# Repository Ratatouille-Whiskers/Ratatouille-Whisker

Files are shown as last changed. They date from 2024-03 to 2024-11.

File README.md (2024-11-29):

# Ratatouille-Whisker



Watch the video (https://www.youtube.com/watch?v=xYr4nw6rwZE)

## Bill of Materials

| Part | Description | Quantity | Cost |
| --- | --- | --- | --- |
| 3-axis Magnetometer | [Adafruit Wide-Range Triple-axis Magnetometer - MLX90393](https://www.adafruit.com/product/4022) | 1 | £10-£20 |
| Microcontroller | [Raspberry Pi Pico](https://www.raspberrypi.com/products/raspberry-pi-pico/) | 1 | £4-£12  |
| 3D Printer Filament | [eSun PLA 1kg Spool](https://esun3dstore.com/collections/pla/products/esun-epla-lite-1-75mm-3d-filament-1kg) | 1 | £18 |
| Silicone | [BBDINO Super Elastic Silicone](https://www.bestbuysilicone.com/collections/all-bbdino-product/products/bbdino-super-elastic-silicone-mold-making-rubber-platinum-trial-kit) | 1 | £28 |
| Magnet | [1 Tube (10 disks) of 5mm x 2mm Magnet](https://uk.rs-online.com/web/p/neodymium-magnets/2192248) | 1 | £8 |
| Demolding Agents | [Demoulding Vaseline](https://en.pebeo.com/catalogue/vaseline-de-demoulage-gedeo) | 1 | £6 |

## Tools & Equipment

- Required
  - 3D Printer (0.4mm nozzle)
  - Soldering Iron
  - Craft Knife (or equivalent)
- Recommended
  - Prusaslicer (2.7.0 or higher)
  - Deburring Tool

## Software Setup

### General Information

Ratatouille-Whisker is powered by a Raspberry Pi Pico. The Pi Pico was chosen for its low cost and dual-core architecture. One core is responsible for receiving and processing data from the magnetometer through I2C, and the other is responsible for transmitting the results over UART to a computer for post-processing.

The Arduino IDE was used to develop the necessary firmware. The Arduino IDE is a convenient wrapper for the Raspberry Pi Pico SDK and enables rapid prototyping. Developing using the Raspberry Pi Pico SDK is also recommended by the Ratatouille-Whisker team but would require additional development time for library integration.

The [arduino-MLX90393](https://github.com/Ratatouille-Whiskers/arduino-MLX90393) library was forked and modified from Teddy Yapo's original library (see relevant [repo](https://github.com/tedyapo/arduino-MLX90393)). The library was modified to allow I2C addresses to be defined manually in the `begin()` function. The modification was necessary as the sensor boards the team was experimenting with featured I2C addresses that did not align with the respective documentation.

A Python script is also provided as a simple serial port listener (using the `pyserial` library) and logger.

### Step 1: Arduino IDE Setup

Download the official Arduino IDE from [here](https://www.arduino.cc/en/software).

Open up the Arduino IDE and go to `File > Preferences`.
In the dialog that pops up, enter the following URL in the "Additional Boards Manager URLs" field:
```
https://github.com/earlephilhower/arduino-pico/releases/download/global/package_rp2040_index.json
```
Hit *OK* to close the dialog.
Go to `Tools > Boards > Board` Manager in the IDE and type "pico" in the search box and select the entry by "Earle F. Philhower".

[For more information visit the original repository [here](https://github.com/earlephilhower/arduino-pico).]

Open `whisker_firmware.ino` under `software/whisker_firmware` using the Arduino IDE. Select Raspberry Pi Pico as the current board.

Compilation will fail as `MLX90393.h` does not exist.

### Step 2: Install the MLX90393 Library

Go to the library's repository ([here](https://github.com/Ratatouille-Whiskers/arduino-MLX90393)) and click on `Code > Download ZIP`. The library can be installed following the instructions listed [here](https://support.arduino.cc/hc/en-us/articles/5145457742236-Add-libraries-to-Arduino-IDE). Skip to the *Importing a .zip Library* and *Manual installation* sections.

### Step 3: Upload the Code

To upload the sketch, you will need to hold the BOOTSEL button down while plugging in the Raspberry Pi Pico to your computer. Then hit the upload button and the sketch should be transferred and start to run. After the first upload, this may not be necessary as the arduino-pico core has auto-reset support.

### Step 4: Inspect Serial Monitor

In the Arduino IDE, click on `Tools > Serial Monitor` and confirm that values are being printed on the screen.

## Hardware Setup

### Printing Guide

- We provide all the **settings** for both the **Prusa MK3S** and **Prusa Mini** printers

> Other printers have not been tested.

- **`3mf`** project files can be imported directly into your slicing software (we recommend **PrusaSlicer**) for loading in all the part geometries required for printing a complete whisker assembly kit.

> Other slicers have not been tested.

- Using a **0.4mm nozzle** is recommended.

> A smaller nozzle would allow for a better result when printing the whisker shafts - but would result in higher print times. 0.25mm nozzles have been tested only for printing the shaft. Not other small sizes have been tested. Please avoid using nozzles larger than 0.4mm to ensure optimal precision and detail.

#### Slicer Settings

> We are assuming that the user has a basic understanding on how to navigate there own slicing software for their printer. Some good guides for getting familar with PrusaSlicer can be found from [Prusa's Knowledgebase](https://help.prusa3d.com/category/prusaslicer_204) and a nice TLDR-like guide from [Tomshardware](https://www.tomshardware.com/how-to/use-prusaslicer)

> If users already have their own tuned profiles for their printers, then they can try those settings and use the guidance below for some additional advice on printing.

We found the default `quality` settings (for 0.4mm nozzles) with supports enabled (tree/organics are fine to use, and can even result in a cleaner result) worked for printing, only requiring two modifications:

**The `Whisker Shaft` should be printed with a **0.1mm** layer height.**

**Setting `XY Size Compensation` in PrusaSlicer:**

> `XY Size Compensation` ensures the holes in the parts are printed with better dimensional accuracy when sliced, improving the fit of parts in each (e.g., Whisker Shaft into the Whisker Socket).

1. Navigate to the `Print Settings` Tab
2. Enable `Expert` mode in the top write of the page
3. From the navigation bar on the left, go to `Advanced`
4. Scroll down to till you get to the `Slicing` section where you will find `XY Size Compensation`.
   - Set `XY Size Compensation`, or your slicer's equivalent setting, to **-0.1mm** as a recommended starting point for tuning.

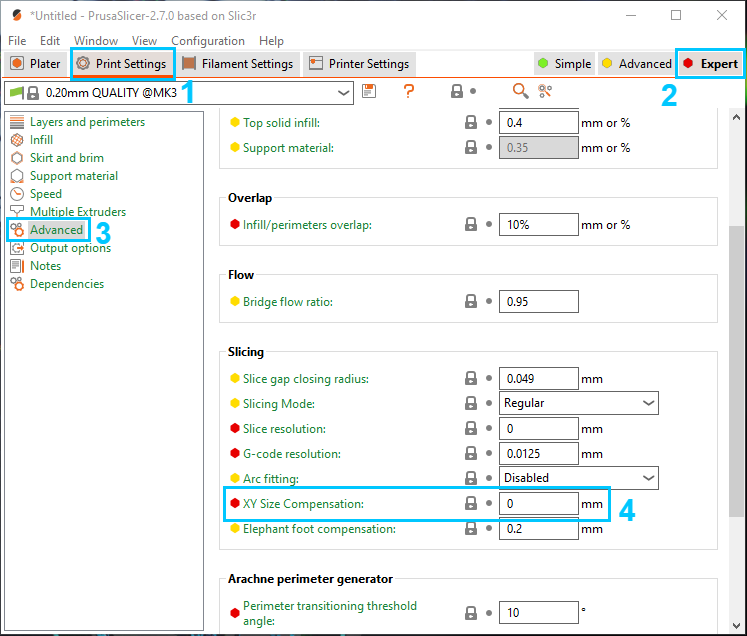
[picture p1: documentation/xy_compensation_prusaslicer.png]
PrusaSlicer XY Compenstation


##### Tuning XY Size Compensation

**DISCLAIMER: DO NOT TAKE THIS TUNING APPROACH AS 'GOOD' ADVICE ON TUNING THIS SETTING FOR ALL PRINTS. IT IS ONLY SUGGESTED FOR PRINTING THESE PARTS AND MAY NOT HELP WITH ALL PRINTS.**

**NOTE: You will need a method to measure an object's inside diameter accurately. We recommend using a set of vernier calipers.**

1. Print a `Whisker Bearing Casting Jig`
2. Print a `Whisker Socket`
3. Ensure the smaller hole of the `Whisker Socket` is approx. `3mm` in diameter
4. Ensure the larger hole of the `Whisker Socket` is approx. `5mm` in diameter
   - If the measurements are as close to "perfect" as the *true* values and the socket is snug but loose enough to fit with the casting jig that it can be easily removed, you should be fine with not tuning the compensation.
5. Set `XY Size Compensation` to `Measured - Expected`
   - Example: measured diameter `2.9mm`, expected diameter `3.0mm`, therefore we set the compensation value to `-0.1mm`
6. Ensure `Whisker Bearing Casting Jig` has a snug fit
   - Repeat this till both holes are as close to *true* as you can possibly and the socket has a snug, but loose enough, fit with the casting jig that it can be easily removed then you should be fine with not tuning the compensation.
7. Repeat steps 1-6 until you achieve high dimensional accuracy and a snug fit

The default PLA settings of the `Prusament PLA` filament profile was used for all prints.

**Note:** You may find that the fit of the `Whisker Base` is too tight in the casting jig (even with the small chamfers in the design aimed to reduce this), and it is therefore recommended to scrape each of the outer edges of the print with a knife (or deburring tool) to deburr the edges and prevent sticking, in addition to the use of mold release agent. **It is especially important for the areas of the `Whisker Base` that were on the print bed and in contact with the brim when printing.**

### Whisker Build Instructions

To Build the whisker make sure you have printed:

- 1 x Whisker Base
- 1 x Whisker Socket
- 1 x Whisker Shaft
- 1 x Whisker Bearing Casting Jig

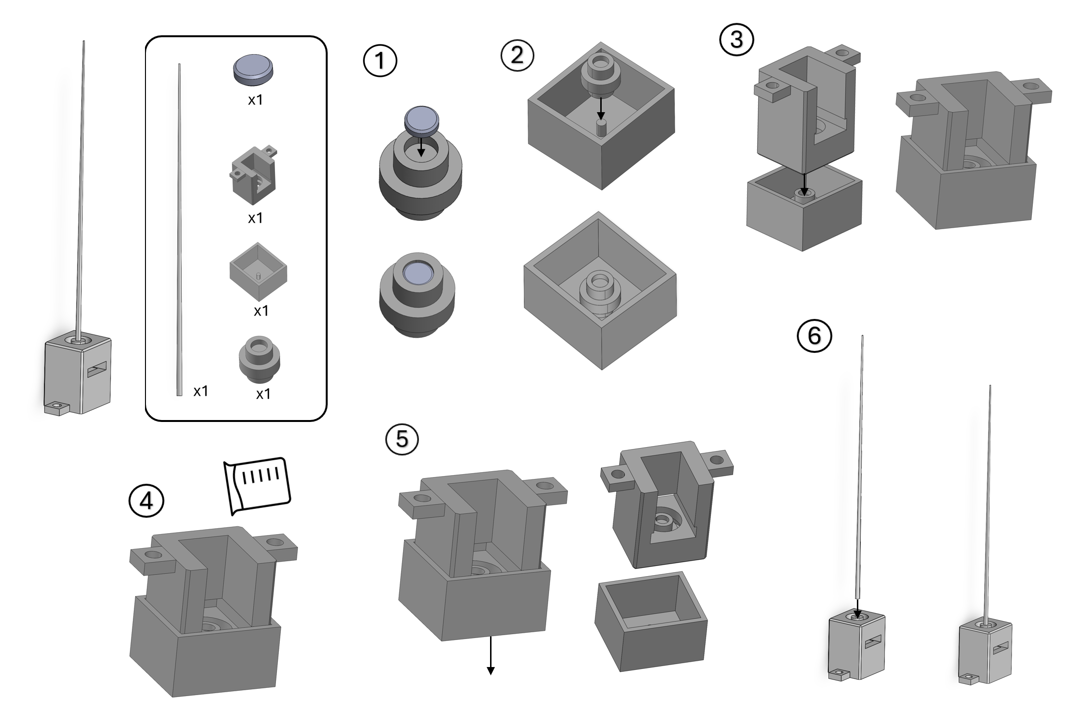
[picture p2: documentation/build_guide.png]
Build Guide Image


1. Glue the magnet into the socket.
2. Place the socket with the magnet attached into the jig. The magnet should face upwards. The pin should slot in easily to secure it in place.
3. Place the base firmly into the jig.
4. Prepare your silicone mixture as per the instructions on the packet. Then pour the silicone mixture into the hole around the socket carefully.
5. Remove the jig carefully, leaving the silicone and the socket in place.
6. Flip the base right-side-up (see image). Place the whisker into the hole in the socket at the top. This may need a gentle push to fit firmly into place.

### Sensor Wiring Instructions

The demo firmware (`whisker_firmware.ino`) implicitly indicates a recommended wiring configuration, as seen by:

```c
#define DRDY_pin 21
#define SDA_pin 16
#define SCL_pin 17
```

In detail, please adhere to the following wiring diagram (format `[SENSOR] -- [PICO]`):

- `VIN -- VBUS`
- `GND -- GND`
- `SCL -- GP17`
- `SDA -- GP17`
- `INT -- GP21`

Please consult the wiring diagram:

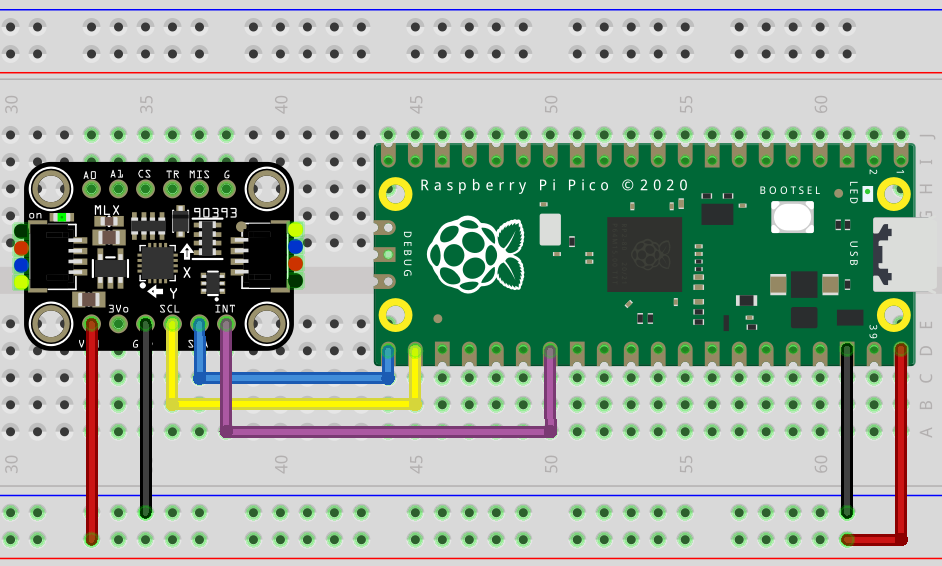
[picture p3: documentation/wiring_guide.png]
Sensor Wiring Guide Image


---

If you wish to use a STEMMA QT / Qwiic JST SH 4-Pin cable, you need only connect `INT` to `GP21` and change the defines to read:

```c
#define DRDY_pin 21
#define SDA_pin 4
#define SCL_pin 5
```

## User Guide

### Logging Data

You are free to use the Python-based script to collect data and save them in a CSV format with timestamps.
Apart from installing Python (from [here](https://www.python.org/)), you also need to install pyserial (see the [repo](https://github.com/pyserial/pyserial)) using pip:
```
pip install pyserial
```

You can now navigate to `software/whisker_listener` and run `python whisker_listener.py -h` to be greeted with useful instructions on how to use the script:

```
usage: whisker_listener.py [-h] [-b BAUD_RATE] serial_port

Read data from a serial port.

positional arguments:
  serial_port   Serial port name (e.g., COM3 or /dev/ttyACM0)

options:
  -h, --help    show this help message and exit
  -b BAUD_RATE  Baud rate (default is 115200)
```

On Linux systems, the data can be logged using:
```
python whisker_listener.py /dev/ttyACM0
```

<!-- ## General Testing
## Troubleshooting Guide -->
## Related Work

[Calibration Platform](https://github.com/FoR-Group1/OpenWhisker/tree/main/calibration_platform) - 3D Printer Based Open Source Calibration
Platform for Whisker Sensors.

**DISCLAIMER: This platform has not been tested with the design presented in this repo, therefore modification may be required to use it for our design.**

## How to Contribute?

Feel free to fork this repo and submit pull requests!

## Cite Ratatouille-Whisker

Click `Cite this repository` in the sidebar to cite the most recent version of this repo.

Alternatively, feel free to cite our publication in TAROS 2024:

```
TBA
```

## License
This work is provided under GPL license for the software source code and CERN-OHL-W license for the hardware design and build instructions.

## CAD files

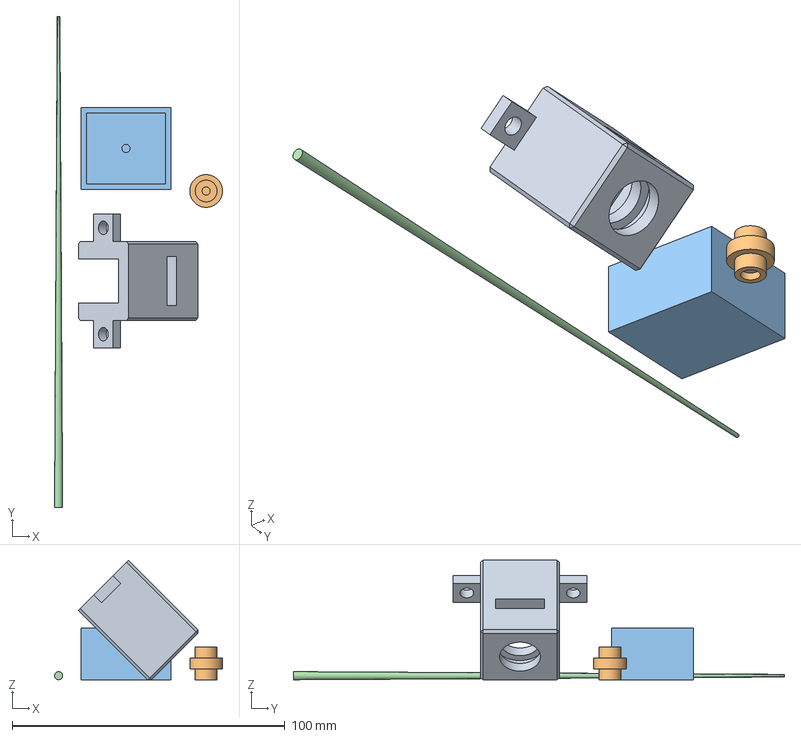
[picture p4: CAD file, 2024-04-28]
hardware/3mf/whisker_whisker_kit_mk3.3mf
61.6 x 180.0 x 43.8 mm
Whisker_Whisker_Base
Whisker_Whisker_Socket
Whisker_Bearing_Casting_Jig
Whisker_Whisker_Shaft

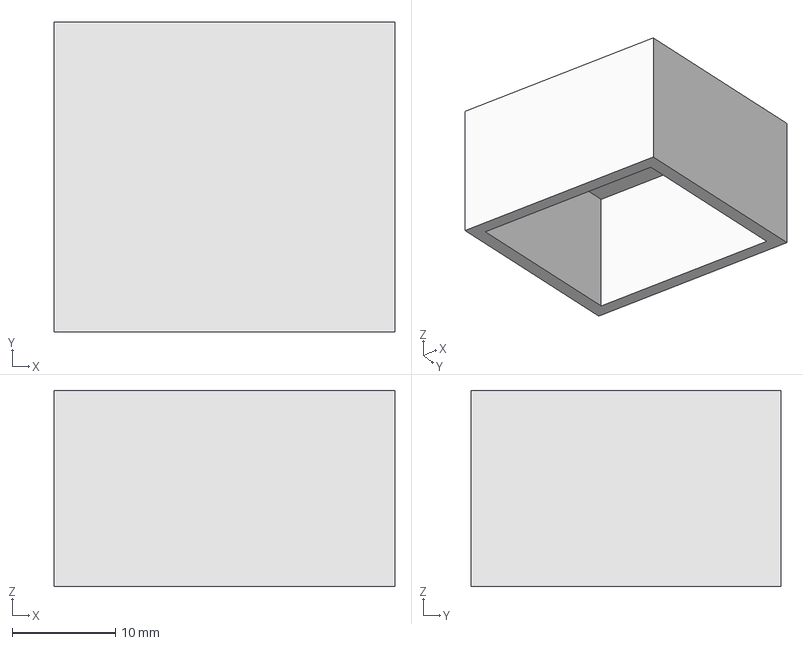
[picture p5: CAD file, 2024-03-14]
hardware/step/whisker_bearing_casting_jig.step
33.0 x 30.0 x 19.0 mm

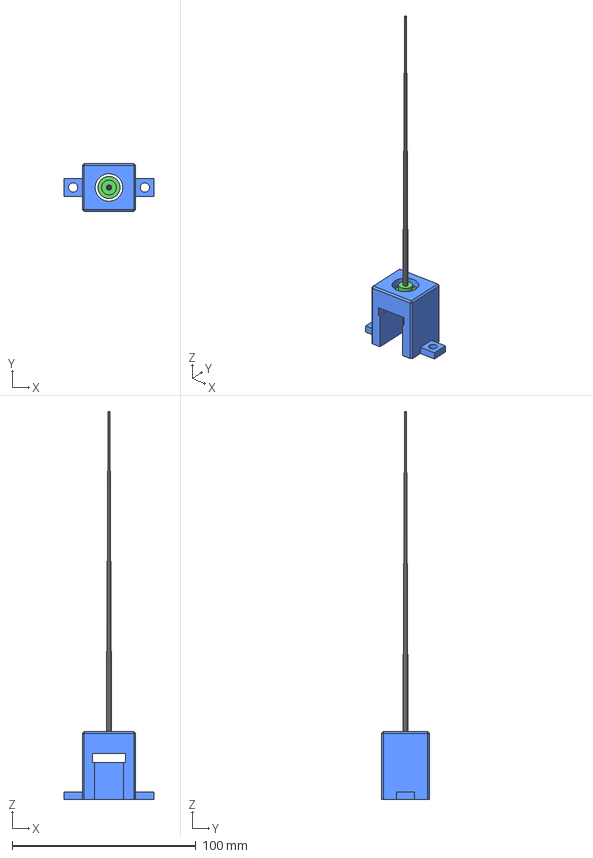
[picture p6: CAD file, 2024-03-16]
hardware/whisker.FCStd
49.0 x 26.0 x 211.0 mm
Whisker Shaft
Whisker Socket
Whisker Base

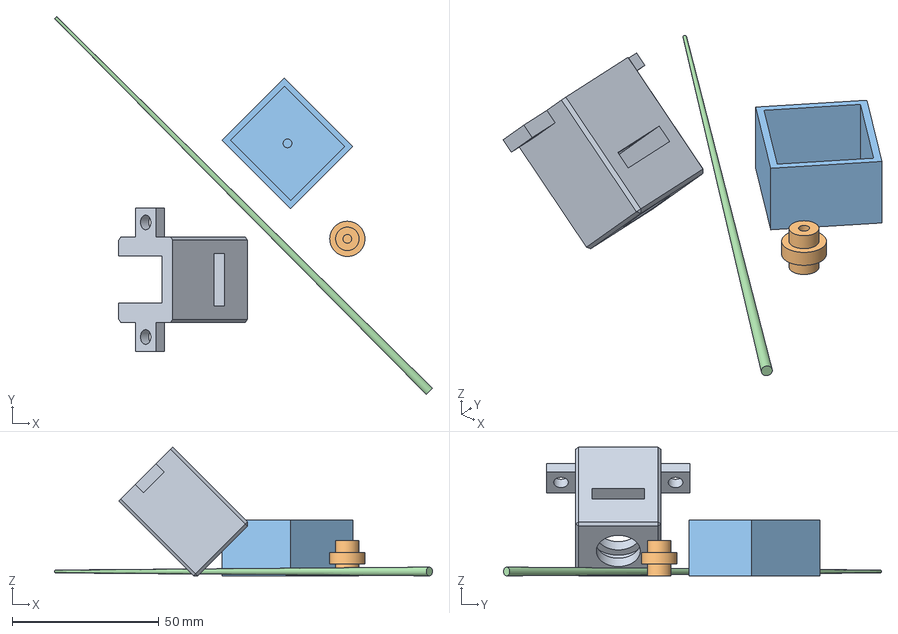
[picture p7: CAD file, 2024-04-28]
hardware/3mf/whisker_whisker_kit_mini.3mf
128.7 x 128.7 x 43.8 mm
Whisker_Whisker_Base
Whisker_Whisker_Socket
Whisker_Bearing_Casting_Jig
Whisker_Whisker_Shaft

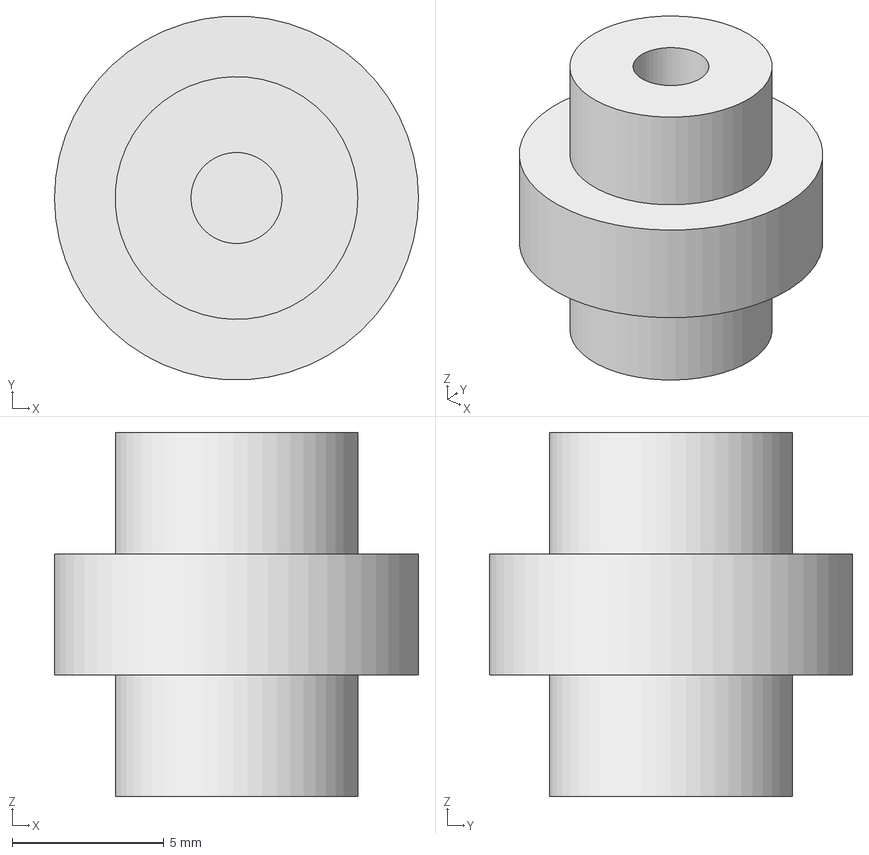
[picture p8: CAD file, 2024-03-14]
hardware/step/whisker_whisker_socket.step
12.0 x 12.0 x 12.0 mm

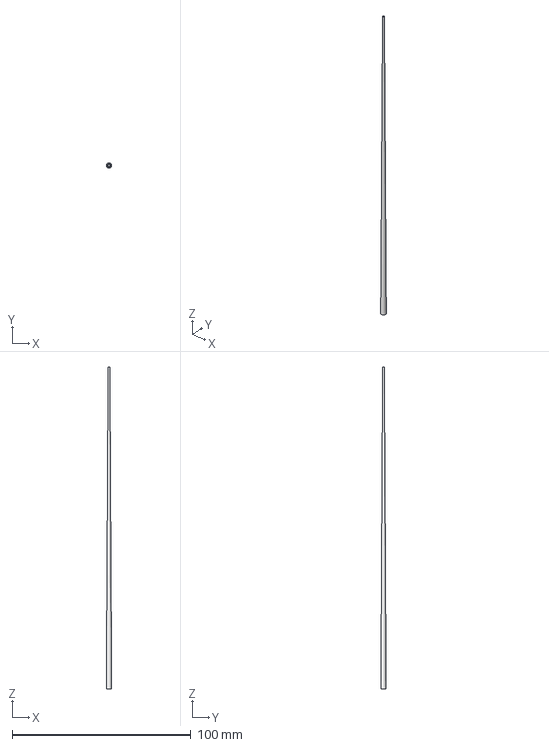
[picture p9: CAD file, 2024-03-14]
hardware/step/whisker_whisker_shaft.step
3.00 x 3.00 x 180.0 mm

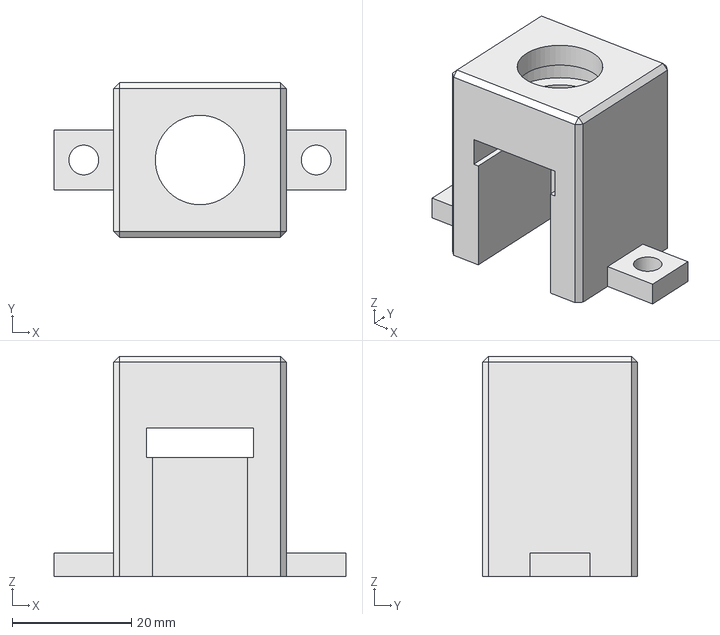
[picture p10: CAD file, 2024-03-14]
hardware/step/whisker_whisker_base.step
49.0 x 26.0 x 37.0 mm

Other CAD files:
hardware/stl/whisker_bearing_casting_jig.stl
hardware/stl/whisker_whisker_base.stl
hardware/stl/whisker_whisker_shaft.stl
hardware/stl/whisker_whisker_socket.stl

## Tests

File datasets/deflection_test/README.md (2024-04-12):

# Test Data

The dataset consists of X,Y,Z axis readings from the magnetometer for deflections of 1-20mm in the structure of: 

The sliced version of the dataset consists of only the y readings. This is the data we are interested in as the deflection is in the y direction. This is for compuational reduction in processing times and conciseness of analysis.  

## About:

Whisker deflection tests

Deflection point: 21mm from the top of the whisker
 
Range:0 to 20mm

Step size: 1mm

Number of steps: 20

Reading structure: 

0-1mm
0-2mm
...
0-20mm

Reading Speed: 1.2khz

Total readings: 1.5mil+

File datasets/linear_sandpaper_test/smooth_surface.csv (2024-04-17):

timestamp | AX | AY | BX | BY | CX | CY
2024-04-17_14:34:06.776762 | 33212 | 33366 | 33854 | 34002 | 32789 | 32939
2024-04-17_14:34:06.780401 | 33229 | 33396 | 33782 | 33999 | 32787 | 32931
2024-04-17_14:34:06.784058 | 33219 | 33374 | 33744 | 34001 | 32763 | 32949
2024-04-17_14:34:06.787722 | 33219 | 33397 | 33769 | 34037 | 32776 | 32932
2024-04-17_14:34:06.791545 | 33227 | 33387 | 33802 | 34080 | 32781 | 32892
2024-04-17_14:34:06.795213 | 33236 | 33382 | 33817 | 34041 | 32792 | 32891
2024-04-17_14:34:06.798729 | 33232 | 33345 | 33794 | 33983 | 32764 | 32907
2024-04-17_14:34:06.802563 | 33233 | 33349 | 33776 | 33993 | 32762 | 32894
2024-04-17_14:34:06.806510 | 33217 | 33344 | 33837 | 33997 | 32768 | 32895
2024-04-17_14:34:06.809853 | 33236 | 33347 | 33871 | 34005 | 32766 | 32891
2024-04-17_14:34:06.813744 | 33246 | 33349 | 33807 | 33977 | 32774 | 32884
2024-04-17_14:34:06.817311 | 33233 | 33387 | 33790 | 33949 | 32761 | 32873
2024-04-17_14:34:06.819697 | 33211 | 33412 | 33795 | 33959 | 32762 | 32879
2024-04-17_14:34:06.823500 | 33210 | 33396 | 33842 | 33972 | 32777 | 32875
2024-04-17_14:34:06.826633 | 33230 | 33396 | 33844 | 33984 | 32769 | 32842
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

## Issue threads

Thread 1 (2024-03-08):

What to put in the BOM?

DimiPaparas, 2024-03-08:
I started a discussion under commit 537c384, but I'm also opening an issue since they are more accessible.

Closed 2024-04-28.

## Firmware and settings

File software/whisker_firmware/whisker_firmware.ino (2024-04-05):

#include <MLX90393.h>
#include <math.h>

#define DRDY_pin 21
#define SDA_pin 16
#define SCL_pin 17

MLX90393 mlx;
MLX90393::txyzRaw rawData;
MLX90393::txyz data;

volatile bool dataReady = false;
volatile bool procReady = false;
volatile uint8_t status_flag = MLX90393::STATUS_ERROR;

// To include Z-axis measurements use
// MLX90393::X_FLAG | MLX90393::Y_FLAG | MLX90393::Z_FLAG
const uint axisFlags = MLX90393::X_FLAG | MLX90393::Y_FLAG | MLX90393::Z_FLAG;

void mlxInterrupt()
{
    dataReady = true;
}

void setup()
{
    Serial.begin(115200);
    while (!Serial)
    {
        delay(10);
    }

    pinMode(DRDY_pin, INPUT_PULLDOWN);
    attachInterrupt(DRDY_pin, mlxInterrupt, RISING);

    Wire.setSDA(SDA_pin);
    Wire.setSCL(SCL_pin);
    Wire.setClock(400000);
    Wire.begin();

    byte status = mlx.begin(0x18, DRDY_pin, Wire);

    mlx.setGainSel(0);
    mlx.setOverSampling(0);
    mlx.setDigitalFiltering(0);
    mlx.setResolution(1, 1, 1);
    mlx.setTemperatureCompensation(0);

    mlx.startBurst(axisFlags);
}

void loop()
{
    if (dataReady)
    {
        dataReady = false;
        status_flag = mlx.readMeasurement(axisFlags,rawData);
        if(status_flag != MLX90393::STATUS_ERROR){
          data = mlx.convertRaw(rawData);
          procReady = true;
        }
    }
}

void loop1()
{
    if (procReady)
    {
        procReady = false;

        if (axisFlags & MLX90393::X_FLAG)
            Serial.printf(">X: %f\r\n", data.x);

        if (axisFlags & MLX90393::Y_FLAG)
            Serial.printf(">Y: %f\r\n", data.y);

        if (axisFlags & MLX90393::Z_FLAG)
            Serial.printf(">Z: %f\r\n", data.z);
    }
}

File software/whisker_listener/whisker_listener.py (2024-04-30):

import serial
from datetime import datetime
import argparse


def read_serial_port(port, baud_rate):
    try:
        ser = serial.Serial(port, baud_rate)
        print(f"Reading from serial port {port} at {baud_rate} baud rate...\n")

        x_val = None
        y_val = None
        z_val = None

        timestamp = datetime.now().strftime("%Y-%m-%d_%H_%M_%S")
        with open(f"whisker_{timestamp}.csv", "a") as datafile:
            datafile.write("timestamp,x,y,z\n")
            while True:
                timestamp = datetime.now().strftime("%Y-%m-%d_%H:%M:%S.%f")
                line = ser.readline().decode("utf-8").strip()

                if "X" in line:
                    x_val = line.split(" ")[-1]

                if x_val is None: continue

                if "Y" in line:
                    y_val = line.split(" ")[-1]

                if y_val is None: continue

                if "Z" in line:
                    z_val = line.split(" ")[-1]

                if z_val is None: continue
                
                datafile.write(f"{timestamp},{x_val},{y_val},{z_val}\n")

    except serial.SerialException as e:
        print(f"Error: {e}")
        ser = serial.Serial(None)

    finally:
        if ser.is_open:
            ser.close()
            print("Serial port closed.")


if __name__ == "__main__":
    parser = argparse.ArgumentParser(description="Read data from a serial port.")
    parser.add_argument(
        "serial_port", type=str, help="Serial port name (e.g., COM3 or /dev/ttyACM0)"
    )
    parser.add_argument(
        "-b",
        dest="baud_rate",
        type=int,
        default=115200,
        help="Baud rate (default is 115200)",
    )

    args = parser.parse_args()

    read_serial_port(args.serial_port, args.baud_rate)

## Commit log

2024-03-08 Add tentative BOM
2024-03-11 Updated BOM into separate sensor and test setup list
2024-03-11 Update README.md
    Added data for the Raspberry Pi Pico
2024-03-11 Base of the Whisker sensor assembly
    [Whisker-Whisker Base.step]
2024-03-11 (WIP) Whisker FreeCAD file
    This will contain all the required models in one file
    [Whisker.FCStd]
2024-03-11 Increase the Pin Height space for the Whisker Base CAD
    [Whisker-Whisker Base.step, Whisker.FCStd]
2024-03-13 Added Wiring Diagram to Docs
2024-03-14 Created the rest of the Whisker assembly parts
    Added:
    - Socket
    - Shaft
    - Casting Jig
    Updates:
    Whisker Base: Mounting Holes are M3->M5 Size. I added Chamfers to the outer edges to try and help the fitting and removal of the casting jig, which would otherwise be too tight due to a challenge in the printing process for 90-degree corners.
    [Whisker-Bearing Casting Jig.step, Whisker-Whisker Base.step, Whisker-Whisker Shaft.3mf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]
2024-03-16 Make STEP files terminal friendly
    [Whisker_Bearing_Casting_Jig.step, Whisker_Whisker_Base.step, Whisker_Whisker_Shaft.step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]
2024-03-16 Update Whisker.FCStd
    - Bodies are now under a part
    - Added Material for each Model body, so that they are distinguishable
    [Whisker.FCStd]
2024-03-17 Add STLs of STEP files
    [Whisker_Bearing_Casting_Jig.stl, Whisker_Whisker_Base.stl, Whisker_Whisker_Shaft.stl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]
2024-03-17 Add sample build instructions
2024-03-29 Added Print settings and considerations
2024-04-02 Create Adafruit MLX90393 QT.step
    [Adafruit MLX90393 QT.step]
2024-04-09 Refined Print instructions
2024-04-09 Updated BOM in README
2024-04-12 Added Interrupt pin signal that when triggered with reverse the servo dir.
    This is so that we can sweep the servo but reverse it if we find that the whisker has detected an obsticale and we want to signal a stop to prevent damaging the whiskers by moving in the opposite direction at a faster rate before resetting back to default sweep speed
2024-04-13 Add tl;dr Arduino IDE setup
2024-04-13 Add wiring guide
2024-04-15 Add first sandpaper test data
    [whisker_2024-04-15_14_05_46.csv]
2024-04-15 Fix dataset
    [whisker_2024-04-15_14_05_46.csv]
2024-04-15 Add new dataset
    [whisker_2024-04-15_14_20_27.csv]
2024-04-15 Add p240 sandpaper test
    [whisker_2024-04-15_14_29_56.csv]
2024-04-16 Upload Stepper Control Firmware for the Test Rig for access
2024-04-16 Radial Distance Test Dataset upload
    [Magnitude_whisker_110_2024-04-16_20_04_11.csv, Magnitude_whisker_95_2024-04-16_20_06_34.csv]
2024-04-17 Add new radial test results
    [deflection_105.csv, deflection_115.csv, deflection_125.csv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]
2024-04-17 Add new sandpaper test
    [p120_test.csv, p240_test.csv, p40_test.csv]
2024-04-17 Add linear sandpaper test results
    [sandpaper_p40.csv, table.csv]
2024-04-19 Moved Print Guide to Hardware Setup
2024-04-27 Moved STL Files from STEP folder to STL folder
    [Whisker_Bearing_Casting_Jig.stl, Whisker_Whisker_Base.stl, Whisker_Whisker_Shaft.stl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]
2024-04-28 Edit printing guide
2024-04-28 Rename datasets
    [deflection_105.csv, deflection_115.csv, deflection_125.csv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]
2024-04-28 Rename design files
    [whisker.FCStd, whisker_bearing_casting_jig.step, whisker_bearing_casting_jig.stl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]
2024-04-28 Uploaded Missing 3mf Files
    [Whisker_Whisker_Kit_MINI.3mf, Whisker_Whisker_Kit_MK3.3mf]
2024-04-28 Moved 3mf to correct folder
    [Whisker_Whisker_Kit_MINI.3mf, Whisker_Whisker_Kit_MK3.3mf]
2024-04-28 Rename 3mf files
    [whisker_whisker_kit_mini.3mf, whisker_whisker_kit_mk3.3mf]
2024-04-28 Added Related Work + Calibration Platform Ref
2024-04-29 Update README.md with printer support setting prompt
